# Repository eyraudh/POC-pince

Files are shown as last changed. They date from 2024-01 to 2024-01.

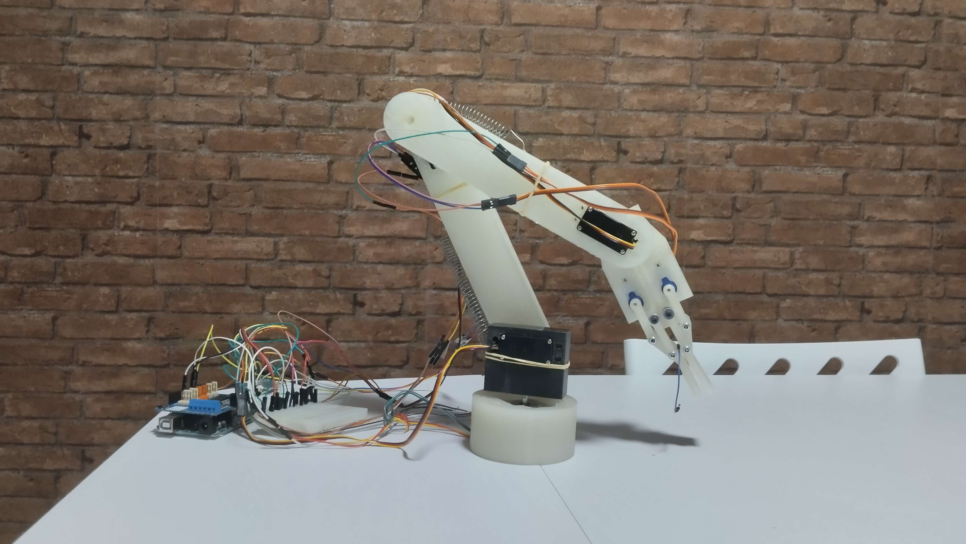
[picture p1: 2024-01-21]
video/bras_eteind.jpg

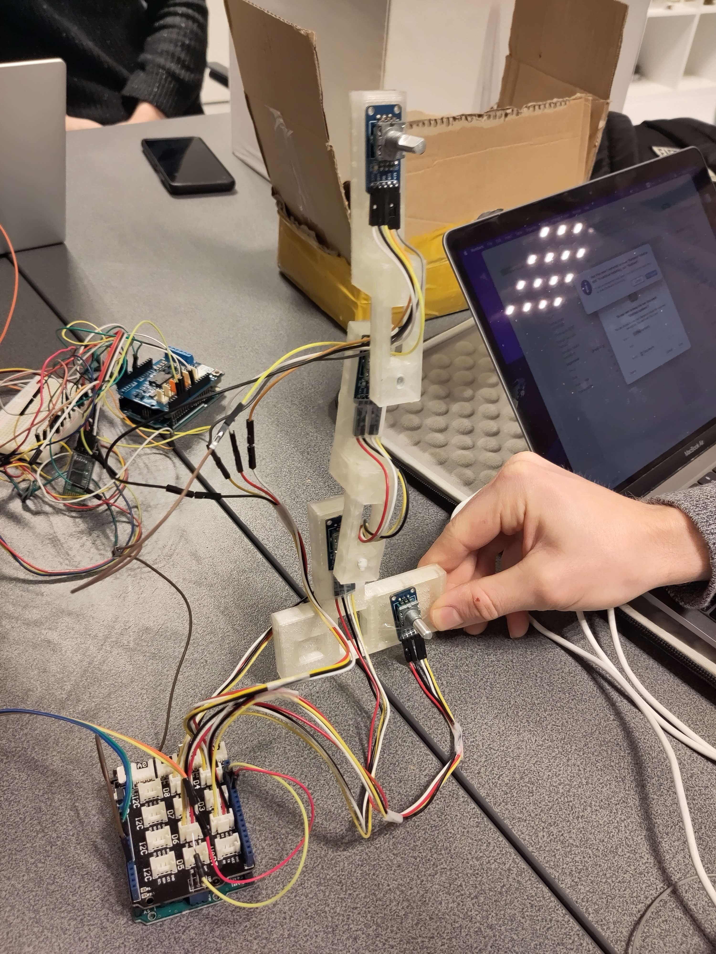
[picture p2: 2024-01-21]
video/bras_commande.jpg

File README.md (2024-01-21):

# projet-objet-connecté
Pour plus d'informations, se référer à la section wiki. L'entièreté du code est trouvable dans la section src. 

* src : code source du bras bras2.ino pour la telecommande et BrasRover.ino pour le bras
* video : photo et video du bras une fois monté
* 3DMODEL : tout les modeles 3D utilisé pour imprimé le bras.

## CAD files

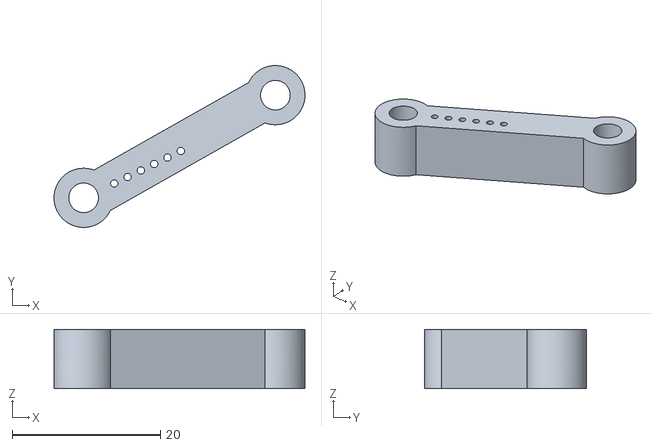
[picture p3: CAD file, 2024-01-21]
3DMODEL/barredh.stl
33.9 x 21.9 x 8.00

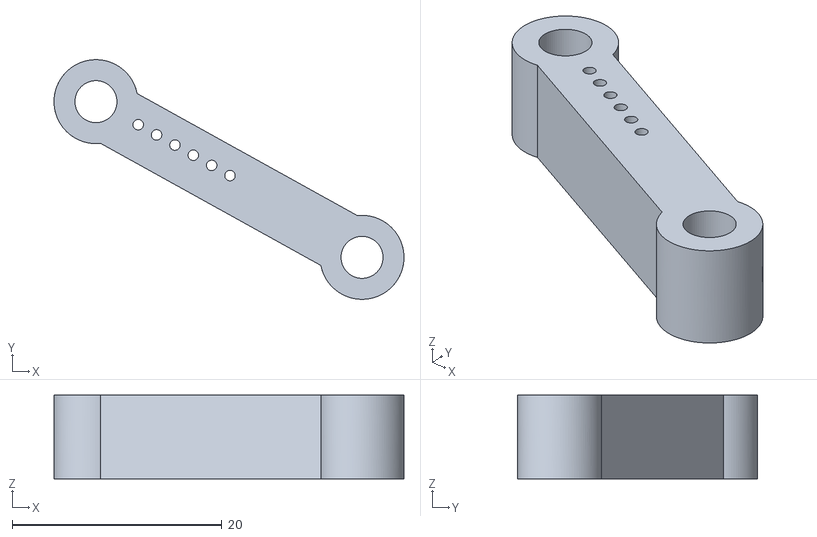
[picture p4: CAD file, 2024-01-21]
3DMODEL/barregh.stl
33.4 x 22.8 x 8.00

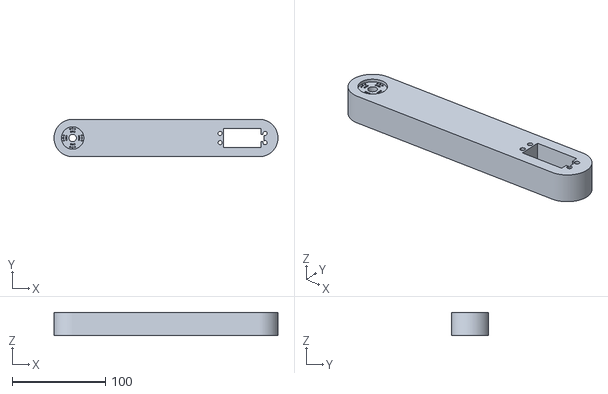
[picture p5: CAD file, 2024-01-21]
3DMODEL/bras1.stl
240.0 x 40.0 x 25.0

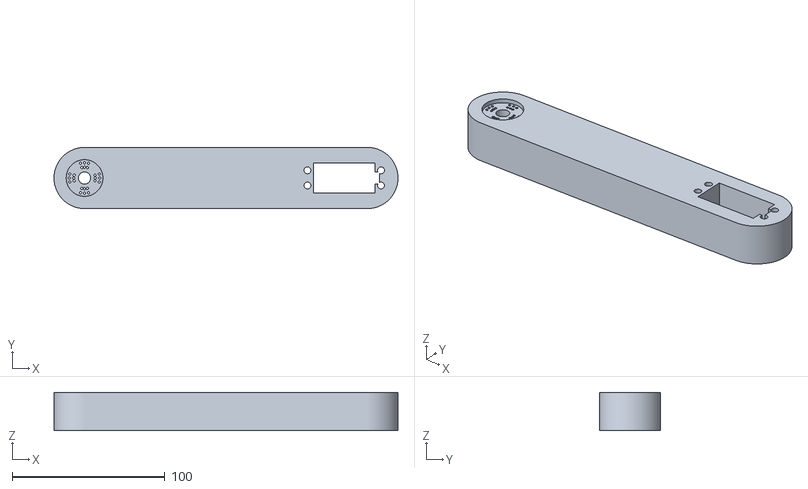
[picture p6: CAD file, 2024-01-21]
3DMODEL/bras2.stl
225.0 x 40.0 x 25.0

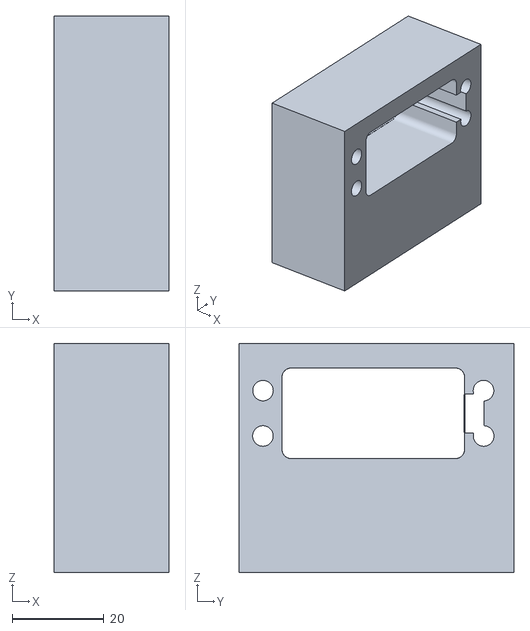
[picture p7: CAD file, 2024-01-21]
3DMODEL/adaptateur.stl
25.0 x 60.0 x 50.0

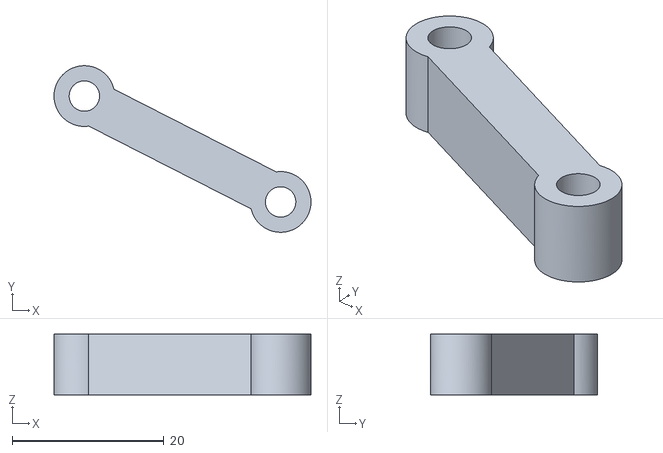
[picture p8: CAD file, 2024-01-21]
3DMODEL/barregb.stl
33.9 x 21.9 x 8.00

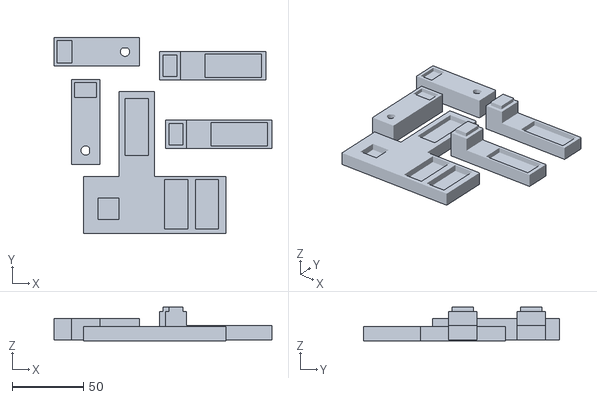
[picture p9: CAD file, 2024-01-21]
3DMODEL/BRAS_2_ALL_PIECE.stl
153.4 x 137.8 x 23.7

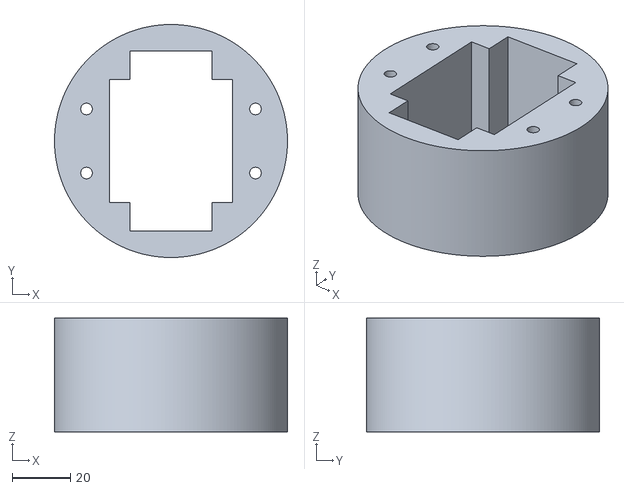
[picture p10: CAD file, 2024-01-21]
3DMODEL/socle.stl
80.0 x 80.0 x 39.0

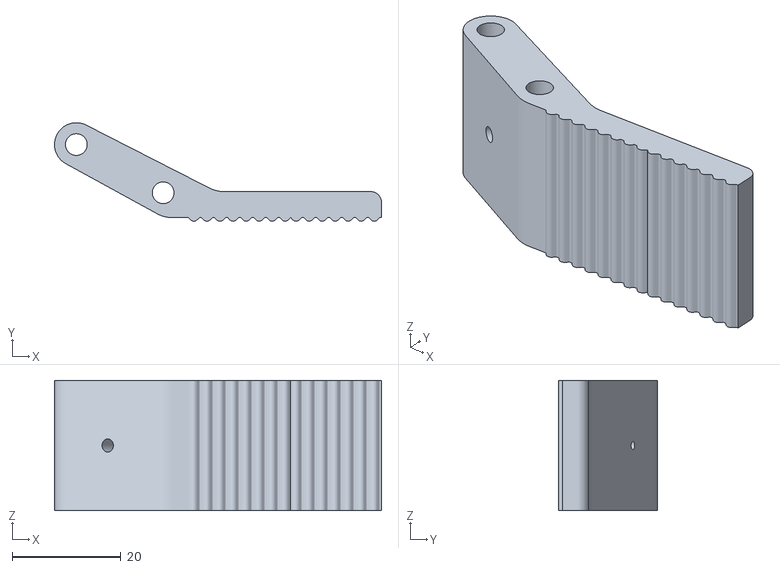
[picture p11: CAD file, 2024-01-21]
3DMODEL/pinced.stl
60.2 x 18.1 x 24.0

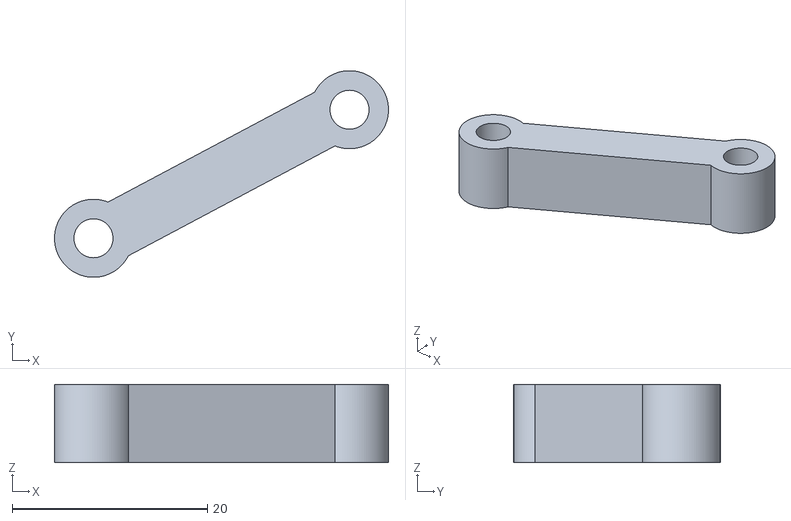
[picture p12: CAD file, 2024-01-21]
3DMODEL/barredb.stl
34.3 x 21.2 x 8.00

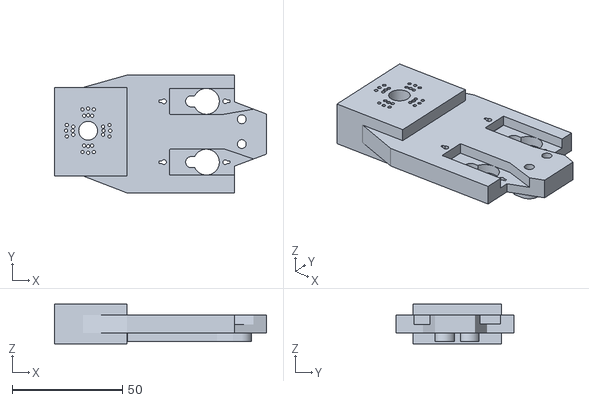
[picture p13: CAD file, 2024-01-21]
3DMODEL/corps_pince.stl
96.0 x 53.4 x 18.0

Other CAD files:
3DMODEL/pinceg.stl

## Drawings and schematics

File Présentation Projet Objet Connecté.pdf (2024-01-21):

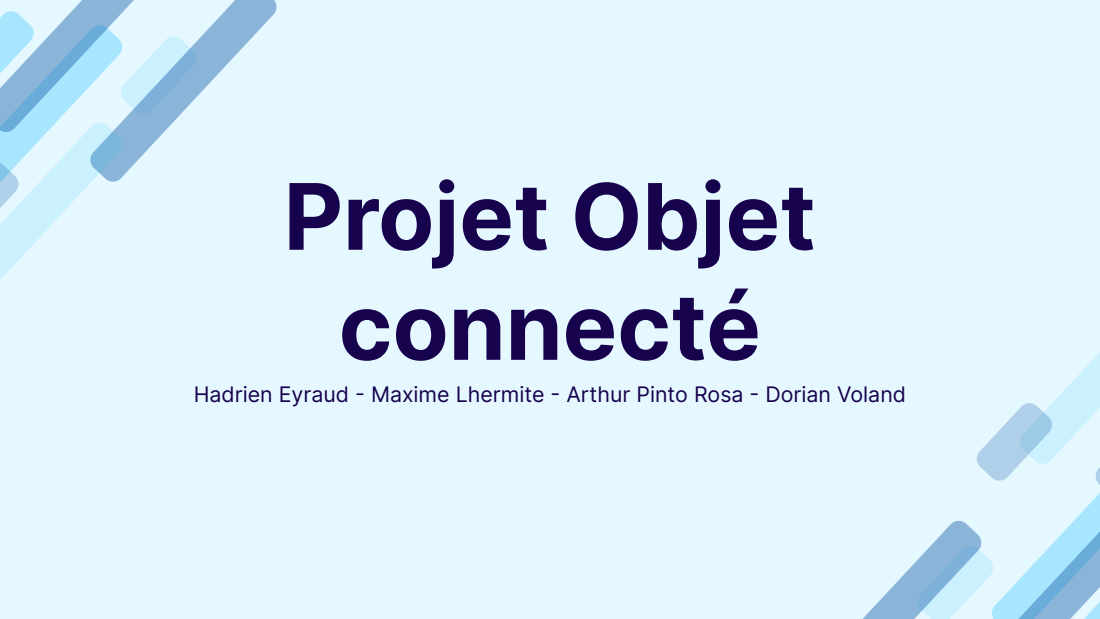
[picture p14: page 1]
Projet Objet connecté

Hadrien Eyraud - Maxime Lhermite - Arthur Pinto Rosa - Dorian Voland

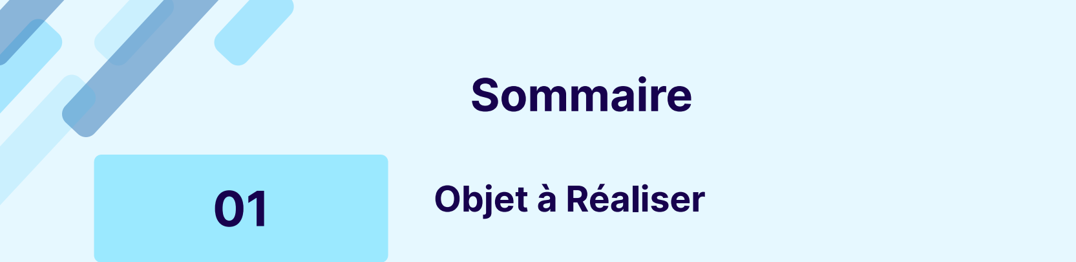
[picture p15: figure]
Sommaire; 01 Objet à Réaliser

# 02 La Conception des Différentes Pièces

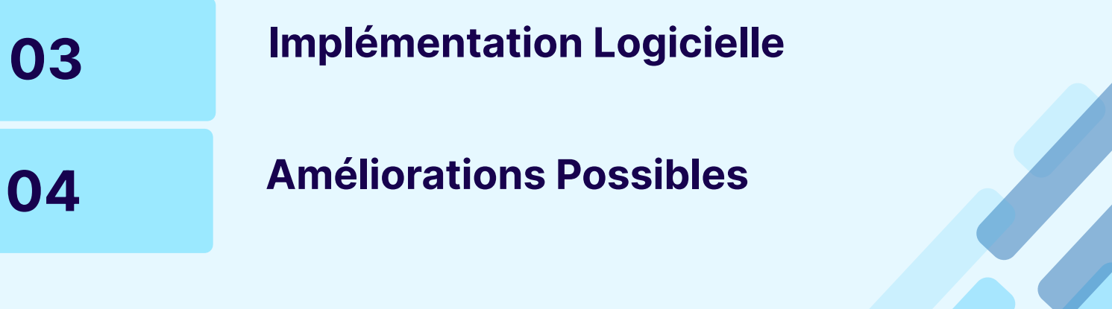
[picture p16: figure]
03 Implémentation Logicielle; 04 Améliorations Possibles

01

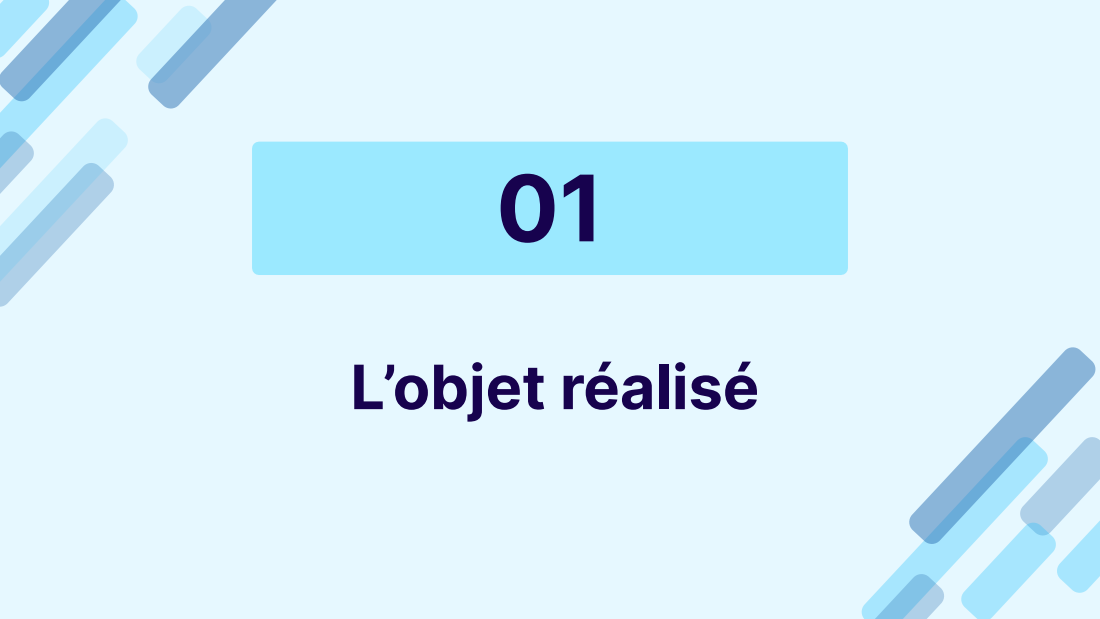
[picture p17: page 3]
L’objet réalisé

# Les bases du projet

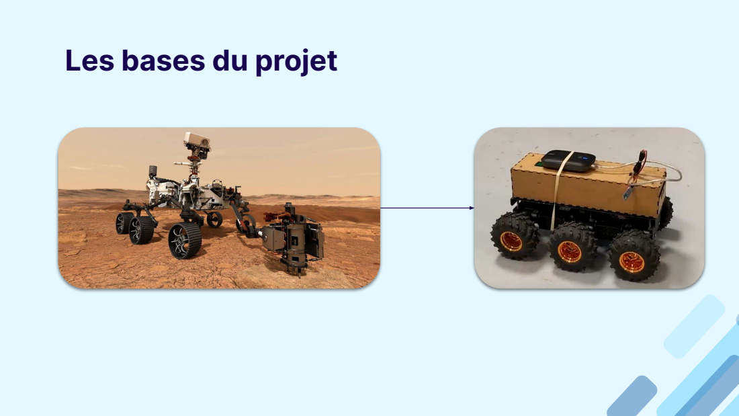
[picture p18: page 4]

# Resultats

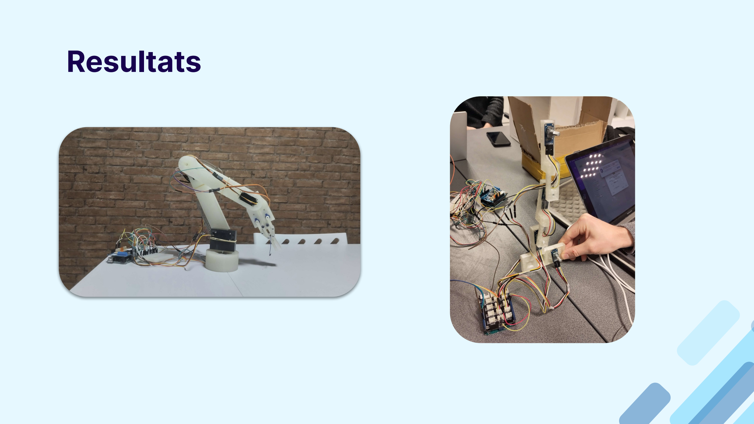
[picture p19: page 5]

# Répartition des tâches

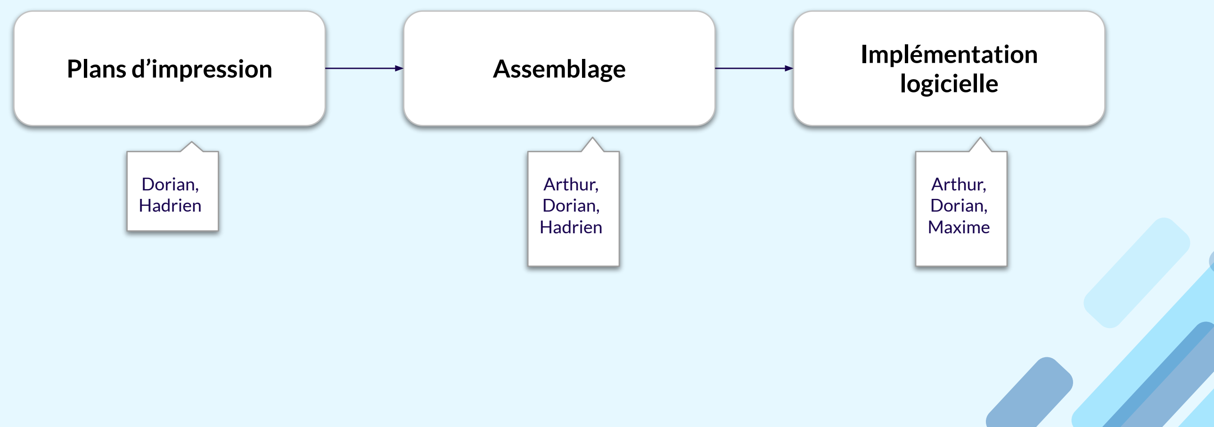
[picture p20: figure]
Plans d’impression; Assemblage; Implémentation; logicielle; Dorian, Hadrien; Arthur, Dorian, Hadrien; Arthur, Dorian, Maxime

# Prix et temps du projet

Impressions

- 15h10 d’impressions
- 13 pièces différentes
- ~ 4,5 euro de plastique
- Temps de conception : ~30h

Piece

- | Arduino Uno x2 | 50e
- | Module Bluetooth HC-05 x2 | 18e
- | Servomoteur HS-485HB x3 | 66e
- | Micro-servo FS90 x2 | 14e
- | Moteur pas à pas Nema17 | 15e
- | Encodeur rotatif waveshare x4 | 14e
TOTAL | ~ 180

02

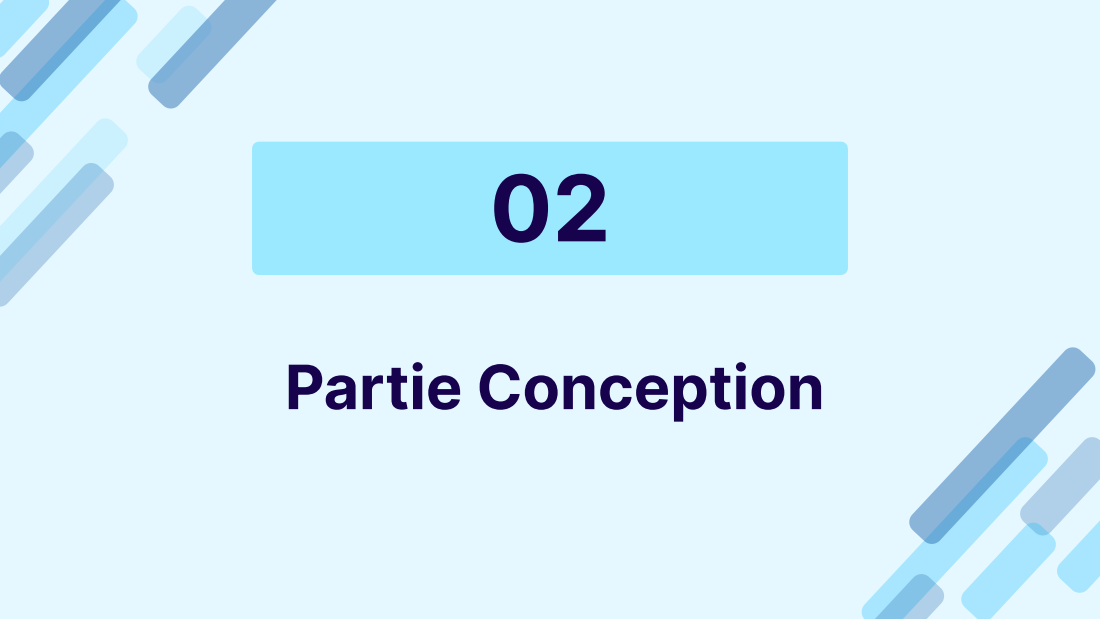
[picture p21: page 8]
Partie Conception

# Impression des différentes pièces

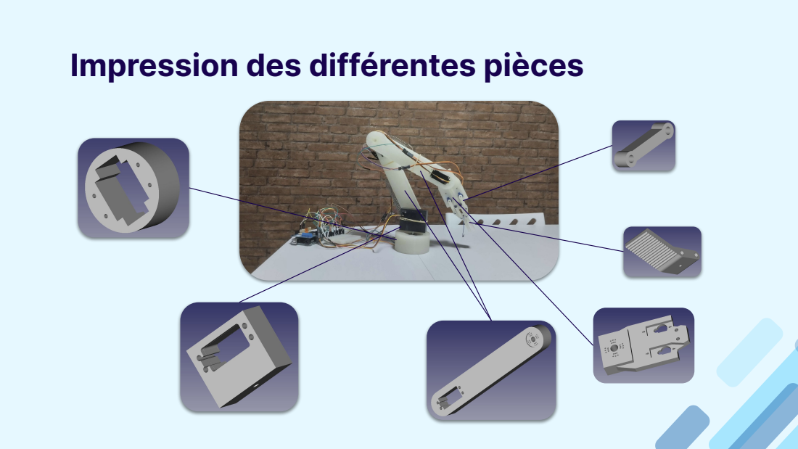
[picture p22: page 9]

# Impression des différentes pièces

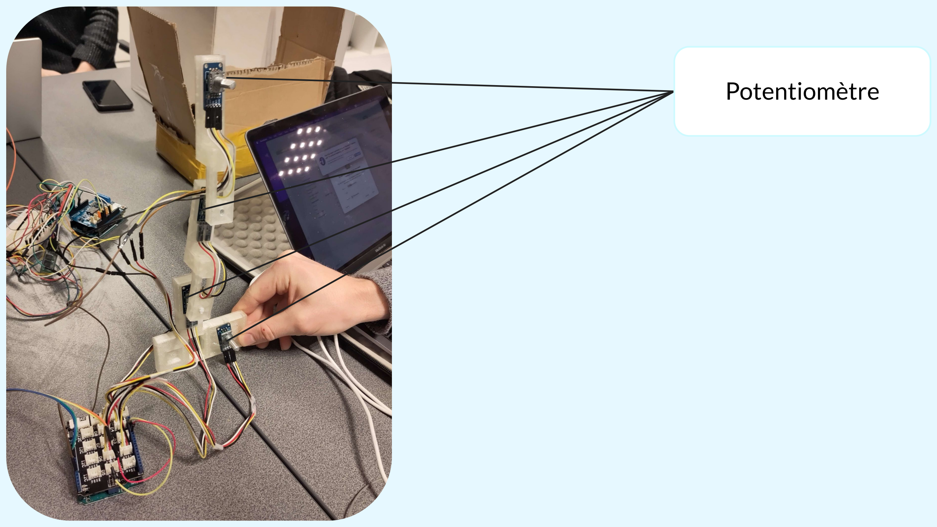
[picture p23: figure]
Potentiomètre
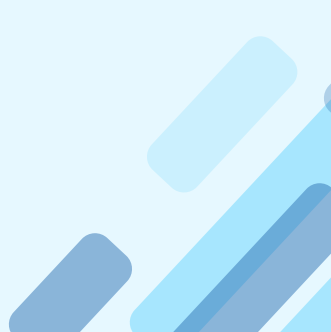
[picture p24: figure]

# Assemblage

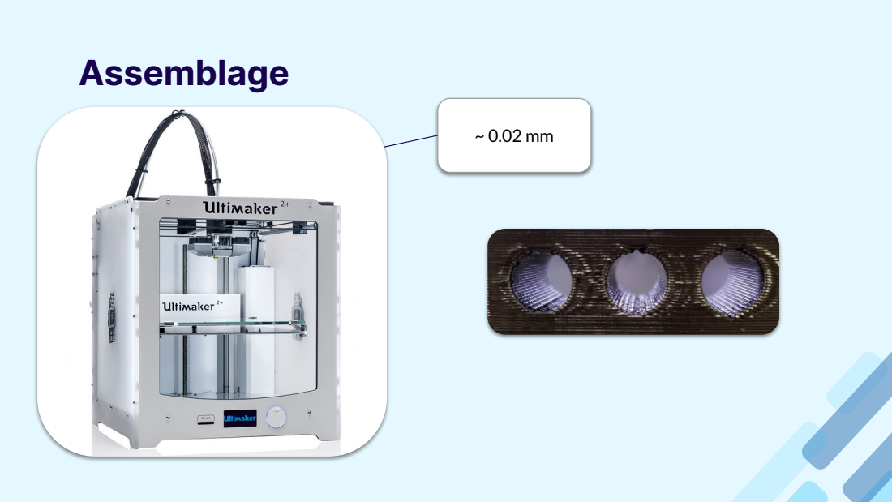
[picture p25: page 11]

03

Partie logicielle

# Les programmes à réaliser

Programme “maître”; et du bouton ● Traduction des positions en trame textuelle envoyée par Bluetooth lorsqu’une des valeurs est mise à jour; Programme “esclave”; ● Initialise la position des moteurs; trame via Bluetooth ● Décode les positions reçues dans les trames ● Envoie l’ordre correspondant aux servomoteurs et à la pince

- Lit les positions des encodeurs rotatifs
- Se place en attente de réception d’une

# Les programmes à réaliser


04

Améliorations Possibles

# Améliorations possibles

● Ajout d’un support/trépied pour stabiliser le rover; ● Remplacement des servomoteurs par des vérins; ● Remplacement des encodeurs rotatifs par des potentiomètres + engrenages; ● Ajout de “grip” à la pince et de capteurs de pression

05

Présentation du prototype

Merci

Avez-vous des questions?

CREDITS: This presentation template was created by Slidesgo, (https://bit.ly/3A1uf1Q) and includes icons
by Flaticon, (http://bit.ly/2TyoMsr) and infographics & images by Freepik (http://bit.ly/2TtBDfr) and content by Swetha Tandri

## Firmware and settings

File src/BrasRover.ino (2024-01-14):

#include <Servo.h>
#include <Stepper.h>

#define RGT_SERVO_CLOSE_ANGLE 80
#define RGT_SERVO_REST_ANGLE 140
#define RGT_SERVO_OPEN_ANGLE 200
#define LFT_SERVO_CLOSE_ANGLE 90
#define LFT_SERVO_REST_ANGLE 44
#define LFT_SERVO_OPEN_ANGLE 2
#define ARM1_SERVO_HIGH_ANGLE 145
#define ARM1_SERVO_REST_ANGLE 145
#define ARM1_SERVO_LOW_ANGLE 50
#define ARM2_SERVO_LOW_ANGLE 40
#define ARM2_SERVO_REST_ANGLE 190
#define ARM2_SERVO_HIGH_ANGLE 180
#define CLAMP_SERVO_LOW_ANGLE 60
#define CLAMP_SERVO_REST_ANGLE 120
#define CLAMP_SERVO_HIGH_ANGLE 270

const int stepsPerRevolution = 200;

#define pwmA 3
#define pwmB 11
#define brakeA 9
#define brakeB 8
#define dirA 12
#define dirB 13

inline float map(float val, float min, float max, float minOut, float maxOut) {
  return val / (max-min) * (maxOut-minOut) + minOut;
}

Stepper base = Stepper(stepsPerRevolution, dirA, dirB);

Servo handRightServo;  // create servo object to control a servo
Servo handLeftServo;
Servo fstArmServo;
Servo sndArmServo;
Servo clampServo;
// twelve servo objects can be created on most boards

int pos = 0;    // variable to store the servo position

void setup() {
  handRightServo.attach(6);  // attaches the servo on pin 9 to the servo object
  handLeftServo.attach(7);
  fstArmServo.attach(5);
  sndArmServo.attach(2);
  clampServo.attach(4);

  // Set the PWM and brake pins so that the direction pins can be used to control the motor:
  pinMode(pwmA, OUTPUT);
  pinMode(pwmB, OUTPUT);
  pinMode(brakeA, OUTPUT);
  pinMode(brakeB, OUTPUT);

  digitalWrite(pwmA, HIGH);
  digitalWrite(pwmB, HIGH);
  digitalWrite(brakeA, LOW);
  digitalWrite(brakeB, LOW);

  // Set the motor speed (RPMs):
  base.setSpeed(20);

  fstArmServo.write(ARM1_SERVO_REST_ANGLE);
  sndArmServo.write(ARM2_SERVO_REST_ANGLE);
  clampServo.write(CLAMP_SERVO_REST_ANGLE);
}

void loop() {
  delay(2000);
  float a = ARM1_SERVO_HIGH_ANGLE;
  for (a = ARM2_SERVO_HIGH_ANGLE; a > ARM2_SERVO_LOW_ANGLE; a -= 0.1)
  {
    sndArmServo.write(floor(a));
    delay(1);
  }
  for (a = ARM1_SERVO_HIGH_ANGLE; a > ARM1_SERVO_LOW_ANGLE; a -= 0.1)
  {
    fstArmServo.write(floor(a));
    delay(1);
  }
  delay(2000);
  for (a = ARM2_SERVO_LOW_ANGLE ; a < ARM2_SERVO_HIGH_ANGLE; a += 0.1)
  {
    sndArmServo.write(floor(a));
    delay(1);
  }
  for (a = ARM1_SERVO_LOW_ANGLE ; a <ARM1_SERVO_HIGH_ANGLE; a += 0.1)
  {
    fstArmServo.write(floor(a));
    delay(1);
  }
  

  // handRightServo.write(RGT_SERVO_OPEN_ANGLE);
  // handLeftServo.write(LFT_SERVO_OPEN_ANGLE);
  // firstArmServo.write(ARM1_SERVO_HIGH_ANGLE);
  // sndArmServo.write(ARM2_SERVO_HIGH_ANGLE);
  // base.step(200);
  // delay(5000);
  // handRightServo.write(RGT_SERVO_CLOSE_ANGLE);
  // handLeftServo.write(RGT_SERVO_OPEN_ANGLE);
  // firstArmServo.write(ARM1_SERVO_LOW_ANGLE);
  // base.step(-200);
  // sndArmServo.write(ARM2_SERVO_LOW_ANGLE);
  // delay(5000);
}

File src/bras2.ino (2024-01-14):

#include "RotaryEncoder.h"
#include <SoftwareSerial.h>

#define BUTTON_PIN 1
#define MAX_ANGLE 180
#define MIN_ANGLE -180
#define k 50

RotaryEncoder encoder1(4, 5);  // (DT, CLK) BASE_ROTATION
RotaryEncoder encoder2(8, 9);  // (DT, CLK) BRAS_2
RotaryEncoder encoder3(2, 3);  // (DT, CLK) PINCE_BASE 
RotaryEncoder encoder4(6, 7);  // (DT, CLK) BRAS_1
RotaryEncoder encoders[4] = {encoder3, encoder4, encoder2, encoder1} ;

SoftwareSerial BTSerial(13, 12); // Changed TX, RX pins to 13, 12

int pos[4] = {0,145,90,120};
int newPos[4] = {-1,-1,-1,-1};
int oldPosPasAPas = 0;
bool isOpen = true;
bool oldValueButton = false;
int index = 0;
int last100Values[k]; 

void setup() {
  BTSerial.begin(38400);
  Serial.begin(9600); // ouvre le port série
  pinMode(BUTTON_PIN, INPUT_PULLUP);
  Serial.println(serialisedString(pos));
}

void loop() {
  updateValues();
}


void updateValues(){

  encoders[0].tick();
  int newpos = encoders[0].getPosition();
  if (newpos != oldPosPasAPas){
    pos[0] = newpos - oldPosPasAPas;
    oldPosPasAPas = newpos;
    Serial.println(serialisedString(pos));
    BTSerial.write(serialisedString(pos).c_str());
  }
  else{
    pos[0] = 0;
  }
  
  for (int i = 1; i < 4; i++){
      encoders[i].tick();
      int newpos = encoders[i].getPosition();
      if (pos[i] != newpos) {
        pos[i] = newpos; 
        Serial.println(serialisedString(pos));
        BTSerial.write(serialisedString(pos).c_str());
      }
    }
  updateIsOpen();
}

int encoderValueToAngle(int value){
  return map(value%20, -20, 20, MIN_ANGLE, MAX_ANGLE);
}

String serialisedString(int pos[4]){
  int tab[4] = {
      0,
      110, // min 45 - 145
      120, // min 40 - 180
      120 // min 60 - 270
  };
  String s = "";
  s += String(pos[0]*10)+":";
  s += String(-encoderValueToAngle(pos[1])+tab[1])+":";
  s += String(encoderValueToAngle(pos[2])+tab[2])+":";
  s += String(-encoderValueToAngle(pos[3])+tab[3])+":";
  s += isOpen;
  s += "q";
  return s;
}

void updateIsOpen()
{
  bool buttonState = analogRead(BUTTON_PIN) <= 0;
  last100Values[index] = buttonState;
  index = (index+1)%k;
  int valueButton = sumTab(last100Values, k);

  if(valueButton != oldValueButton){
    oldValueButton = valueButton;
    if (valueButton){
      isOpen = !isOpen;
      Serial.println(serialisedString(pos));
      BTSerial.write(serialisedString(pos).c_str());
    }
  }
}

bool sumTab(int tab[], int len){
  int sum = 0;
  for (int i = 0; i< len; i++){
    sum += tab[i];
  }
  return sum > len/2;
}

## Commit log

2024-01-14 Bras controller code arduino push
2024-01-21 ajout changement
    [BRAS_2_ALL_PIECE.stl, adaptateur.stl, barredb.stl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]
